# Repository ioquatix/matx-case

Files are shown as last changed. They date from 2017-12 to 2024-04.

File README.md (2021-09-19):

# mATX Case

This repository contains parts for constructing a small (~15L) mATX compatible computer case. It contains both parts which need to be printed, and parts which need to be laser cut.

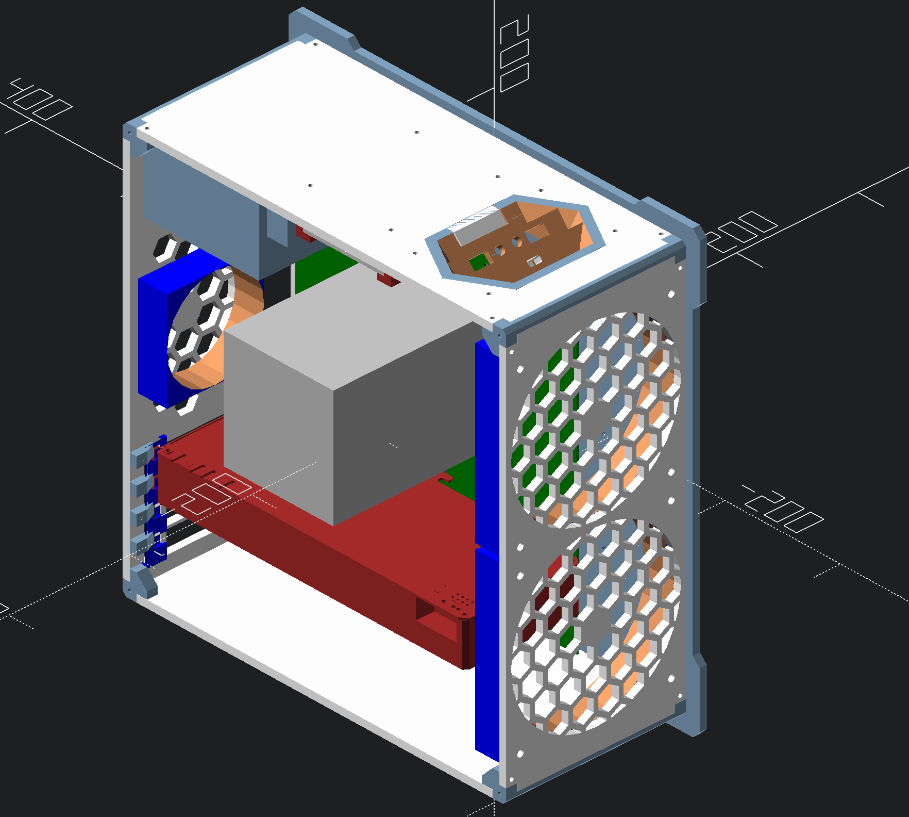
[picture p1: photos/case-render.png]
Case


## Motivation

Ever since I was able to hold a drill, I wanted to make my own computer case. Now, 20 years later, thanks to innovation in 3D printing and laser cutting, it has become trivial to build your own computer case.

In addition, I travel quite a bit and I wanted a computer that was small. Most computer cases are big because of the flexibility it affords. However, being able to print your own case, you can design it specifically for the parts you have in mind. That allows many areas for optimising space.

## Parts Required

- 12mm (6mm thread) brass stand-offs for motherboard.
- ... more stuff ...

### Inventory

- M3 x 12mm (6mm inset) brass standoffs.
- M3 x 6mm (6mm inset) brass standoffs.

- M3 x 12mm flat head screws.
- M3 x 8mm flat head screws.
- M4 x 14mm flat head screws.

- M3 x 8mm (5mm OD) knurled inserts.
- M3 x 10mm (5mm OD) knurled inserts.
- M3 x 12mm (5mm OD) knurled inserts.
- M3 x 6mm (5mm OD) knurled inserts.
- M4 x 8mm (6mm OD) knurled inserts.
- M6 x 12mm (8mm OD) knurled inserts.
- M4 x 4mm (6mm OD) knurled inserts.
- M3 x 4mm (5mm OD) knurled inserts.

### Power Supply

The [Corsair SF600 Platinum][1] has flat SATA cables and fits well.

[1]: https://www.corsair.com/us/en/Categories/Products/Power-Supply-Units/Power-Supply-Units-Advanced/SF-Series/p/CP-9020182-NA

## Instructions

Laser cut and print the parts. You will need to melt the brass knurled inserts into the relevant holes.

## Contributing

1. Fork it
2. Create your feature branch (`git checkout -b my-new-feature`)
3. Commit your changes (`git commit -am 'Add some feature'`)
4. Push to the branch (`git push origin my-new-feature`)
5. Create new Pull Request

## License

Released under the MIT license.

Copyright, 2018, by [Samuel G. D. Williams](http://www.codeotaku.com/samuel-williams).

Permission is hereby granted, free of charge, to any person obtaining a copy
of this software and associated documentation files (the "Software"), to deal
in the Software without restriction, including without limitation the rights
to use, copy, modify, merge, publish, distribute, sublicense, and/or sell
copies of the Software, and to permit persons to whom the Software is
furnished to do so, subject to the following conditions:

The above copyright notice and this permission notice shall be included in
all copies or substantial portions of the Software.

THE SOFTWARE IS PROVIDED "AS IS", WITHOUT WARRANTY OF ANY KIND, EXPRESS OR
IMPLIED, INCLUDING BUT NOT LIMITED TO THE WARRANTIES OF MERCHANTABILITY,
FITNESS FOR A PARTICULAR PURPOSE AND NONINFRINGEMENT. IN NO EVENT SHALL THE
AUTHORS OR COPYRIGHT HOLDERS BE LIABLE FOR ANY CLAIM, DAMAGES OR OTHER
LIABILITY, WHETHER IN AN ACTION OF CONTRACT, TORT OR OTHERWISE, ARISING FROM,
OUT OF OR IN CONNECTION WITH THE SOFTWARE OR THE USE OR OTHER DEALINGS IN
THE SOFTWARE.

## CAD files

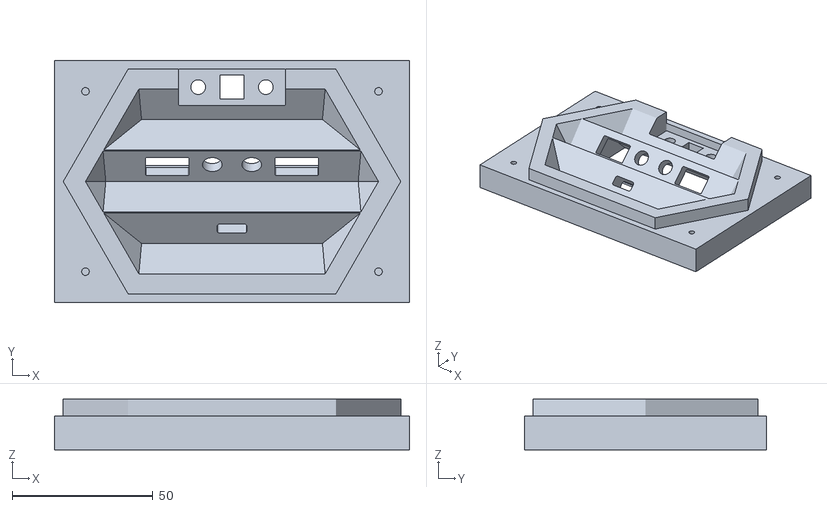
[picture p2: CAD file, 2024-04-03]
build/bay.stl
126.0 x 86.0 x 18.0

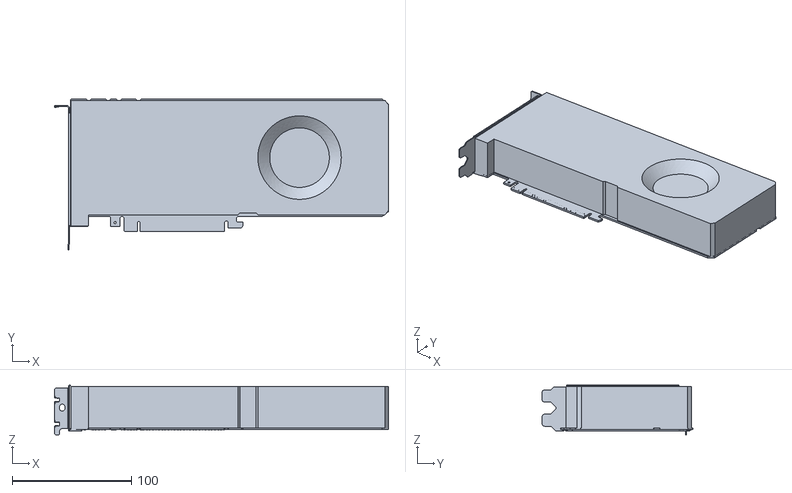
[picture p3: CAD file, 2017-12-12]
source/gtx.stl
280.2 x 126.4 x 41.9

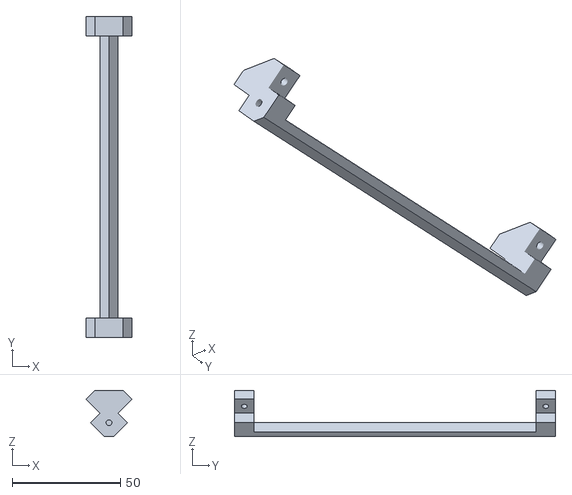
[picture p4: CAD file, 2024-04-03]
build/corner.stl
21.1 x 148.0 x 21.2

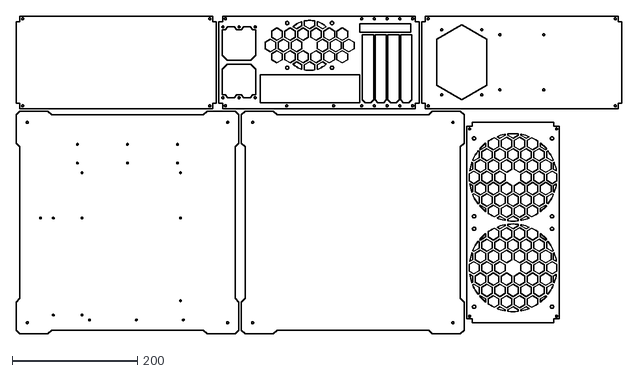
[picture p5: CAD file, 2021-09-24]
build/panels.dxf
968.0 x 508.0

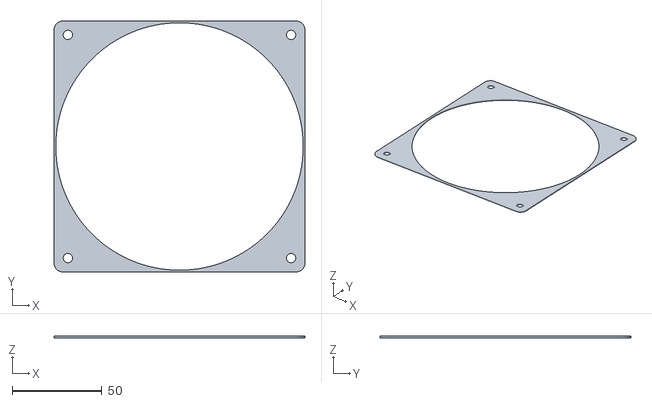
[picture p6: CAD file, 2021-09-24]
build/fan_bracket.stl
140.0 x 140.0 x 1.00

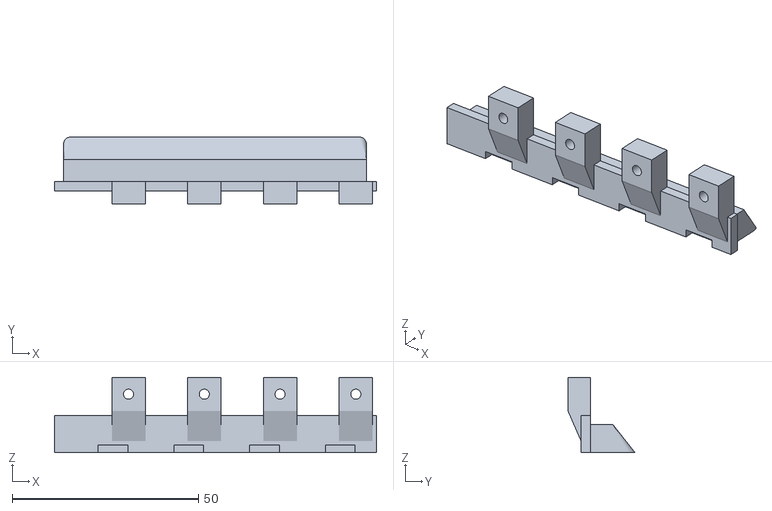
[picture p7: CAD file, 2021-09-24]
build/pci_rear_bracket_top.stl
86.4 x 18.0 x 20.2

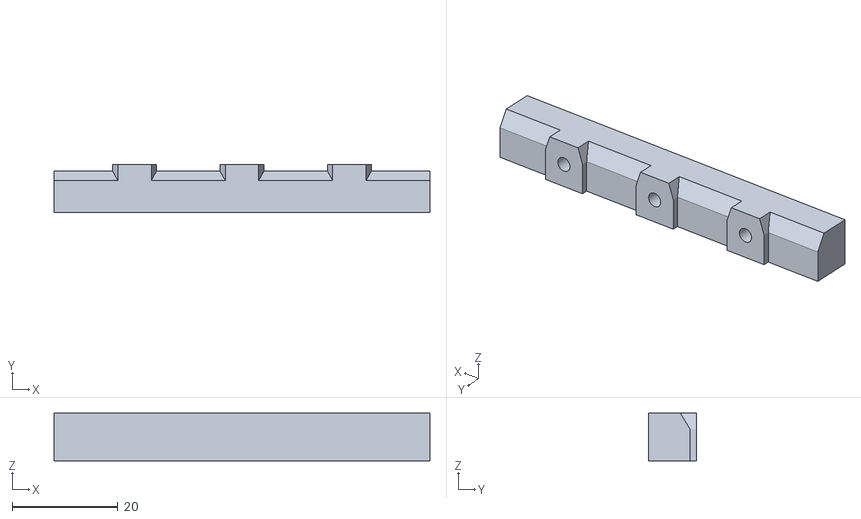
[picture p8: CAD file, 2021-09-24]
build/pci_rear_slots.stl
71.1 x 9.00 x 9.00

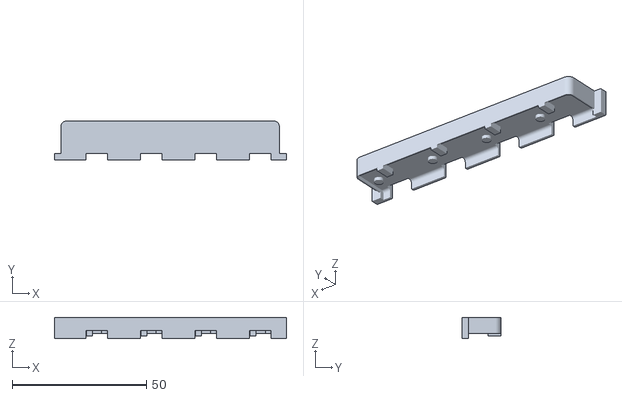
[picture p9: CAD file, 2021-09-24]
build/pci_rear_bracket_bottom.stl
86.4 x 14.5 x 8.00

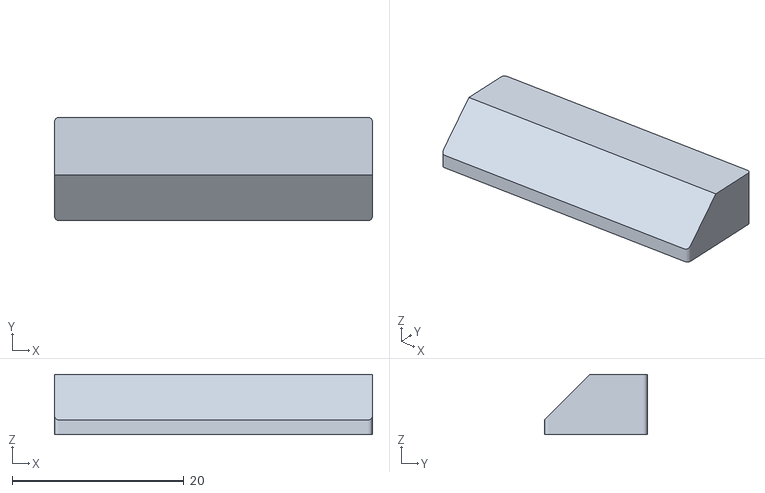
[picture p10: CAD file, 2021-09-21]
build/bay_button.stl
37.0 x 12.0 x 7.00

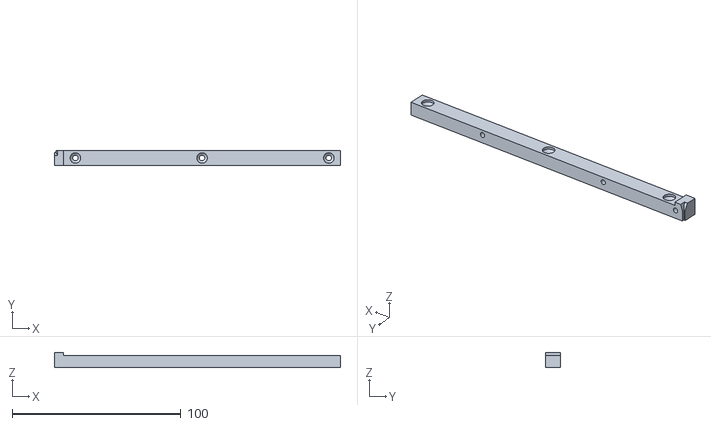
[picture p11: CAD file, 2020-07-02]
build/atx_io_support.stl
169.3 x 9.00 x 9.00

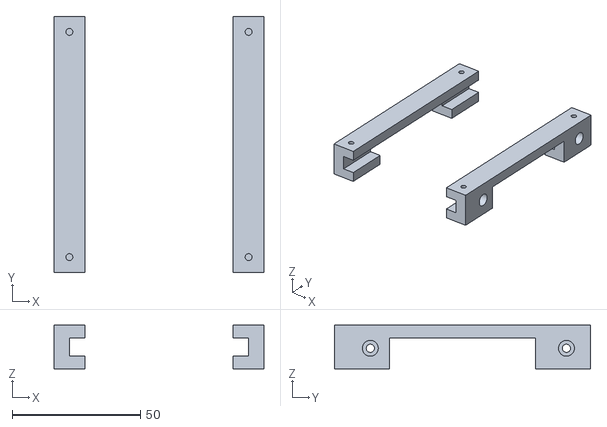
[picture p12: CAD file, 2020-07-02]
build/ssd.stl
82.0 x 100.0 x 17.0

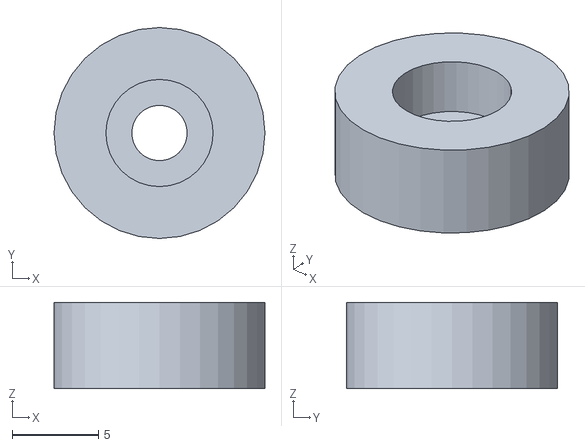
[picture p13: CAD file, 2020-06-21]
build/spacer-panel.stl
12.3 x 12.3 x 5.00

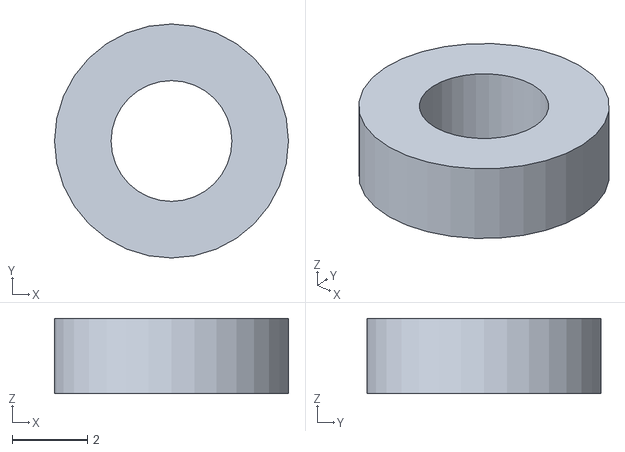
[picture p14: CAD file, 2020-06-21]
build/spacer.stl
6.23 x 6.23 x 2.00

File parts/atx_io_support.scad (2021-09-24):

include <../source/case.scad>;

atx_io_support();

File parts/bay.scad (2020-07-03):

include <../source/case.scad>;

//bay();
bay_button();

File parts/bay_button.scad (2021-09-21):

include <../source/case.scad>;

bay_button();

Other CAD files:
parts/case.scad
parts/corner.scad
parts/duct.scad
parts/fan_bracket.scad
parts/panels.scad
parts/pci_rear_bracket_bottom.scad
parts/pci_rear_bracket_top.scad
parts/pci_rear_slots.scad
parts/ssd.scad
source/bay.scad
source/bolts.scad
source/cable.scad
source/case.scad
source/clip.scad
source/duct.scad
source/fan.scad
source/h115i.scad
source/matx.scad
source/pci.scad
source/projections.scad
source/sfx.scad
source/spacer.scad
source/ssd.scad
source/zcube.scad

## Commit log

2017-12-12 Initial layout.
    [bolts.scad, gtx.stl, matx.scad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]
2017-12-12 External enclosure.
    [matx.scad, zcube.scad]
2017-12-13 Add front fans.
    [matx.scad]
2017-12-13 Better cutout thickness to protrude through case.
    [matx.scad]
2017-12-13 Fix motherboard position.
    [matx.scad]
2017-12-13 Remove one PCI card.
    [matx.scad]
2017-12-13 Parametric case size. Case cutouts.
    [fan.scad, h115i.scad, matx.scad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]
2017-12-13 Better PCI mounting bracket.
    [matx.scad]
2017-12-13 Experimenting with masking out the walls for printing.
    [matx.scad]
2017-12-13 Adjust case so internal box at z=0
    [matx.scad]
2017-12-14 Add holes to corners, resize to suit.
    [bolts.scad, corner.scad, fan.scad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]
2017-12-14 Reworker corner joints to allow printing as two parts
    [matx.scad]
2017-12-15 Full size corner test.
    [corner.scad, corner.stl, matx.scad]
2017-12-15 Experiments with bottom panel.
    [bottom_panel.scad, matx.scad]
2017-12-16 Printed bottom panel... results in a moderate amount of warping.
    [bolts.scad, bottom_panel.scad, bottom_panel.stl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]
2017-12-23 Improved botto tray.
    [bottom_panel.scad, fan.scad, matx.scad]
2018-11-13 Improve component mounts.
    - Fix issue with PCI alignment/size.
    - Add front bay.
    - Fix fan size.
    - Add SSD mounts.
    - Tons of other stuff.
    [bay.scad, bottom_panel.scad, fan.scad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]
2018-11-13 Back PCI panel bracket.
    [matx.scad]
2018-11-13 Projection of wall (error).
    [matx.scad]
2018-11-14 Start creating projections.
    [case.scad, projections.scad, sfx.scad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]
2018-11-14 Add projections for laser cutting.
    [panels.scad, walls.scad]
2018-11-14 More visible color.
    [h115i.scad]
2018-11-14 Smoother circle cutout.
    [fan.scad]
2018-11-14 Better organisation of parts and improve cylinder resolution.
    [case.scad, corner.scad, panels.scad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]
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2018-12-04 Add inset to zsides.
    [zcube.scad]
2018-12-04 Support multiple radiators.
    [h115i.scad]
2018-12-04 Add preview for parts generation.
    [preview.scad]
2018-12-04 Rotate panel so that the laser cutter works on the same side.
    [panels.scad]
2018-12-04 Internal corner mounts.
    [case.scad]
2018-12-12 Improve bottom panel layout. Improve SSD mount. Improve PCI cutout.
    [bottom_panel.scad, bottom_panel.stl, case.scad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]
2018-12-13 Parial rework of PCI bracket.
    [case.scad, pci.scad]
2018-12-14 Rework PCI brackets. Add fan to top panel.
    [case.scad, fan.scad, pci.scad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]
2018-12-16 Printing out PCI brackets.
    [bolts.scad, case.scad, pci.scad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]
2018-12-16 Fix pitch calculation.
    [bolts.scad]
2018-12-16 Add an inset for the notch.
    [pci.scad]
2020-05-19 Preparing to rework internal layout.
    [case.scad, clip.scad, pci_rear_bracket_bottom.stl]
2020-05-19 Updated internal layout.
    [bolts.scad, case.scad, clip.scad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]
2020-05-20 Add SSD mount and rework bay. Add basic cable management.
    [bay.scad, cable.scad, case.scad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]
2020-05-21 Fix preview.
    [bolts.scad, cable.scad, case.scad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]
2020-05-22 Tidy up handling of standoffs.
    [cable.scad, case.scad]
2020-05-22 Add noctua d9l fan+heatsink module.
    [fan.scad]
2020-05-22 Improve preview for A4 layout.
    [preview.scad]
2020-05-22 Improve preview layout for laser cutting.
    [preview.scad]
2020-05-22 Minor rework of internal layout, validation of screw hole sizes.
    [bolts.scad, case.scad, fan.scad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]
2020-05-22 Initial GPU duct.
    [case.scad, duct.scad]
2020-05-22 Complete side vent.
    [case.scad, duct.scad]
2020-06-18 Use M3 bolts for corner holes to allow better structural strength.
    [case.scad, corner.stl]
2020-06-18 Validate hole size and position.
    [sfx.scad, ssd.scad]
2020-06-18 Tidy up remainder of holes.
    [bay.scad, duct.scad, ssd.scad]
2020-06-18 Remove top panel.
    [case.scad]
2020-06-19 Printing corner prototypes.
    [corner.stl]
2020-06-19 First prototype panels.
    [panels.dxf]
2020-06-21 Add spaces for 16mm screws.
    [spacer-panel.stl, spacer.scad, spacer.stl]
2020-06-21 Initial rework of PCI brackets.
    [bolts.scad, case.scad, corner.scad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]
2020-06-21 Updated corner without knurled inserts.
    [corner.stl]
2020-06-23 Improve strength of rear panel.
    [bolts.scad, case.scad, duct.scad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]
2020-06-23 Improve slot design.
    [case.scad, pci.scad, pci_rear_slots.stl]
2020-06-24 Increase width of PCI slots and prepare for 2nd prototype.
    [case.scad, pci.scad, preview-rear-panel.dxf]
2020-07-01 Prepare for 2nd prototype.
    [case.scad, duct.scad, pci.scad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]
2020-07-01 v3 panels.
    [preview-v3.dxf]
2020-07-01 Ensure PCI slot bracket holes are cut in bottom panel.
    [case.scad, pci_rear_bracket_bottom.stl, pci_rear_bracket_top.stl]
2020-07-01 Updated PCI rear braket.
    [case.scad, pci.scad, pci_rear_bracket_bottom.stl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]
2020-07-01 Updated bay design.
    [bay.scad, case.scad, duct.scad]
2020-07-02 Rework various parts for latest prototype, design bay with button.
    [atx_io_support.stl, bay.scad, bay.stl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]
2020-07-02 USB / Audio cutout in bay.
    [bay.scad]
2020-07-02 Updated top bay.
    [bay.scad, bay.stl, bay_button.stl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]
2020-07-03 Updated bay button.
    [bay.scad, bay_button.stl]
2020-07-04 Add fan bracket for avoiding fans clipping filters.
    [fan.scad, fan_bracket.scad]
2020-07-04 Prepare duct for printing.
    [duct.scad, duct.stl]
2021-09-13 Updated build parts.
    [panels.dxf, pci_rear_bracket_bottom.stl, pci_rear_bracket_top.stl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]
2021-09-14 Show bottom panel in case preview.
    [case.scad]
2021-09-14 Extra heat sink/fan combos.
    [case.scad, fan.scad]
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2021-09-18 Tidy up final build.
    [case.scad, panels.scad, preview-rear-panel.scad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]
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2021-09-19 Angleed cable bay to accommodate USB-C port.
    [bay.scad]
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2021-09-19 Minor tweaks to PCB screw positions.
    [bay.scad]
2021-09-21 Prepare bay and bay_button parts for printing.
    [bay.scad, bay.stl, bay_button.scad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]
2021-09-21 Allow fan cutout to follow preview/render resolution.
    [fan.scad]
2021-09-21 Improve bay surround and hexagon cutout.
    [bay.scad, bay.stl, bay_button.stl]
2021-09-21 Prefer square corners for consistency with other parts.
    [bay.scad]
2021-09-21 Tweak USB-C cut out.
    [bay.scad, bay.stl]
2021-09-24 More parts rendered for printing.
    [bay_button.stl, case.scad, duct.stl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]
2021-09-24 Remove duct and add missing atx_io_support part.
    [atx_io_support.scad]
2021-09-24 Don't bother with top cable restraints.
    [case.scad]
2021-09-24 Updated panels for cutting.
    [panels.dxf]
2022-10-25 Better tolerance for bay PCB.
    [bay.scad]
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2024-04-03 Fix bolts.scad for latest scad release.
    [bolts.scad]
